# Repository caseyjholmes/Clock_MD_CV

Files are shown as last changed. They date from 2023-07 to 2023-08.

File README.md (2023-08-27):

# Clock_MD_CV
Modified 4HP 2 channel CV controlled clock multiplier and divider Eurorack Module originally by HAGIWO with PSI power and CV input modifications drawn onto PCB by:
HOLMES MODULAR 7-17-23

Just print a PCB, panel and assemeble acording to BOM. Then program with arduino IDE or atmel studio. 
Check back soon for a note here when the module has been tested and completed/finalized. 7-17-23

This module has been tested and completed. The updated firmware has also been posted. Youtube videos to be posted soon as well as Modular Grid data. 8-23-23
Update: Here's a youtube video showing the module purpose and operation. https://youtu.be/xJtNhXA8xrQ?si=LwXfrnCbjALYdgvX
Modular Grid link coming soon. 
Thanks Hagiwo! I hope my additions are pleasing. 

A BOM update has been added to reflect use of LM40405.0 reference shunt instead of lm40412. This change was a necessary correction due to using renamed component packages in eagle. 8-24-23
This change was also updated in the bottom bom CSV files and schematic.

View this module on Modular Grid
https://www.modulargrid.net/e/other-unknown-holmes-modular-clock-md-cv

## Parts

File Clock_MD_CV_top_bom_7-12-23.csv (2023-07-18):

Comment | Designator | Footprint | LCSC Part #
2.2K bead | L1 | 0603
100n | C4 C13 | C0805K

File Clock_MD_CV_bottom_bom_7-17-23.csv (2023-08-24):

Comment | Designator | Footprint | LCSC Part #
1K | R8 | R0805
1N4148WSF-7 | D5 | SOD-323F
1k | R4 R6 | R0805
10k | R9 R18 | R0805
10n | C7 C8 | C0805K
18p | C9 C10 | C0805K
20mhz | Y1 | CRYSTAL-SMD-5X3.2-2PAD
22k | R2 | R0805
22uf | C1 C2 C5 | PANASONIC_C
100k | R10 R11 R12 R13 R14 R15 R16 R17 | R0805
100n | C6 C11 C12 | C0805K
470 | R1 R3 R5 R7 | R0805
470n | C3 | C0805K
ATMEGA328P | IC1 | TQFP32-08
BAT54CLT1G | D4 | SOT23-3
BAT54SLT1G | D1 D2 D3 | SOT23
FIDUCIAL1X2 | FD1 FD2 FD3 | FIDUCIAL-1X2
LM40405.0 | IC2 | DBZ_R-PDSO-G3
MB1S | B1 | SOIC-4
MCP6002_ | IC4 | SO08
REG1117 | IC3 | SOT223

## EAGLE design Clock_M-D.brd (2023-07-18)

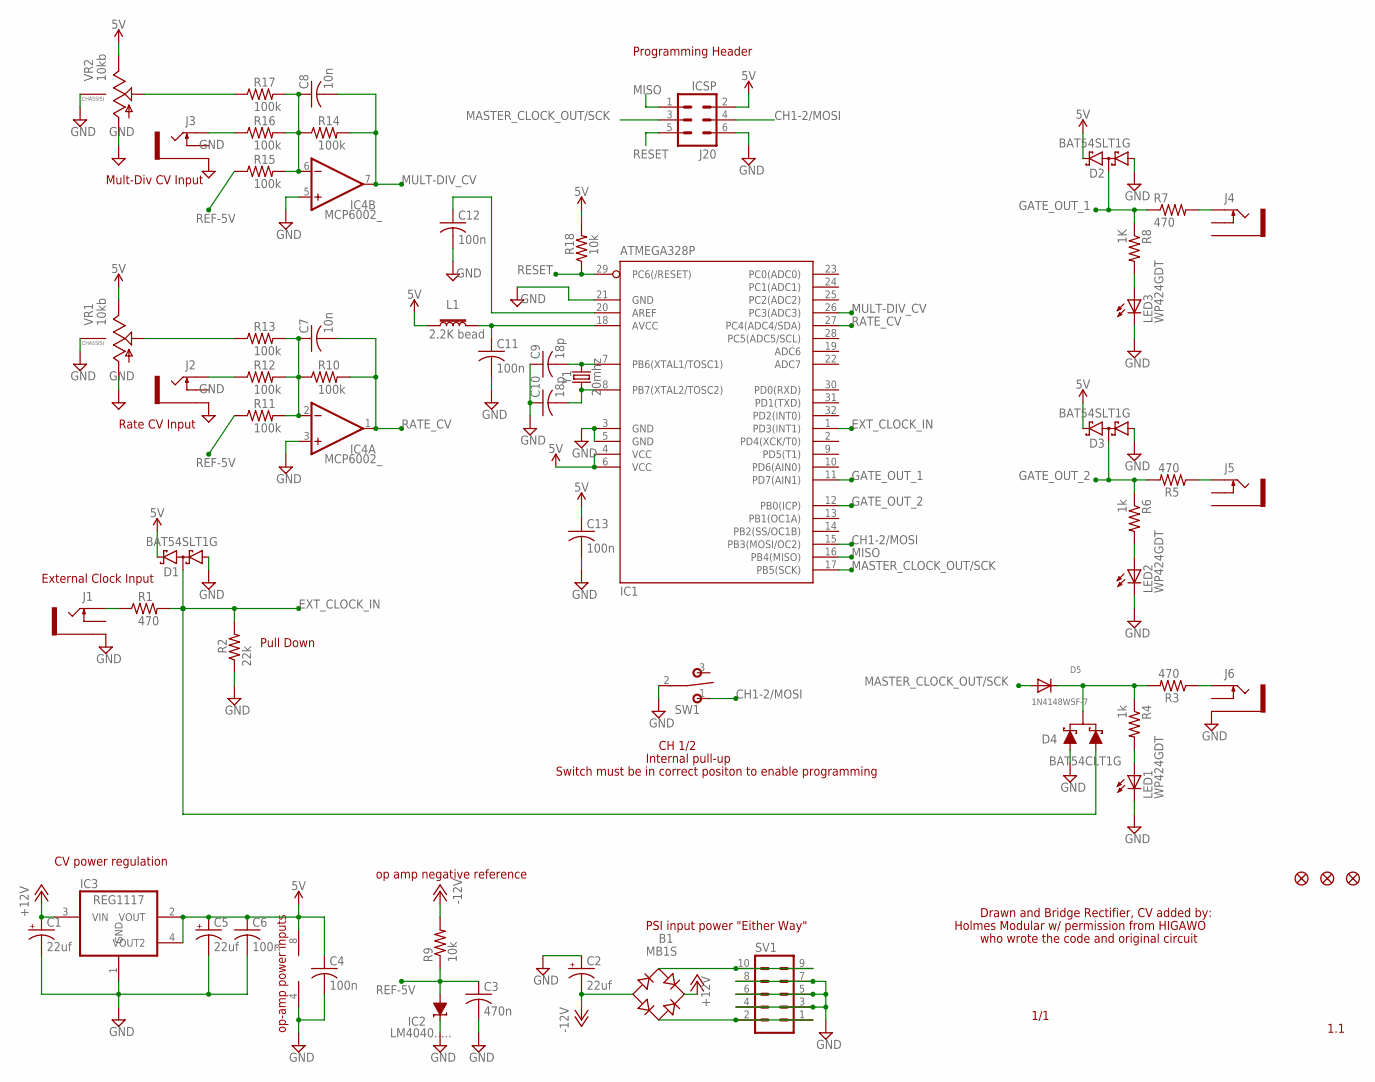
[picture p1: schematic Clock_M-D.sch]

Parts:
B1: MB1S; SOIC-4
C1, C2, C5: 22uf; PANASONIC_C
C3: 470n; C0805K
C4, C6, C11, C12, C13: 100n; C0805K
C7, C8: 10n; C0805K
C9, C10: 18p; C0805K
D1, D2, D3: BAT54SLT1G; SOT23
D4: BAT54CLT1G; SOT23-3
D5: 1N4148WSF-7; SOD-323F
FD1, FD2, FD3: FIDUCIAL1X2; FIDUCIAL-1X2
IC1: ATMEGA328P; TQFP32-08
IC2: LM4040.....; DBZ_R-PDSO-G3
IC3: REG1117; SOT223
IC4: MCP6002_; SO08
J1, J2, J3, J4, J5, J6: THONKICONNNEW; WQP-PJ301M-12_JACK
J20: ICSP; MA03-2
L1: 2.2K bead; 0603
LED1, LED2, LED3: WP424GDT; LED3MM
R1, R3, R5, R7: 470; R0805
R2: 22k; R0805
R4, R6: 1k; R0805
R8: 1K; R0805
R9, R18: 10k; R0805
R10, R11, R12, R13, R14, R15, R16, R17: 100k; R0805
SV1: EURO_POWER_HEADERLOCK; 10PIN_BACKSIDE
SW1: T-80-T-SPDT-ON-OFF-ON; M9040P
VR1, VR2: 10kb; 9MM_SNAP-IN_POT
Y1: 20mhz; CRYSTAL-SMD-5X3.2-2PAD

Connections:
5V: C4.1, C5.+, C6.1, C13.1, D1.2 (C2), D2.2 (C2), D3.2 (C2), IC1.4 (VCC), IC1.6 (VCC), IC3.2 (VOUT), IC3.4 (VOUT2), IC4.8 (V+), J20.2, L1.1, R18.2, VR1.3 (E), VR2.3 (E)
+12V: B1.+, C1.+, IC3.3 (VIN)
-12V: B1.-, C2.-, R9.2
CH1-2/MOSI: IC1.15 (PB3(MOSI/OC2)), J20.4, SW1.1 (O)
EXT_CLOCK_IN: D1.3 (C1A2), D4.2 (A1), IC1.1 (PD3(INT1)), R1.2, R2.2
GATE_OUT_1: D2.3 (C1A2), IC1.11 (PD7(AIN1)), R7.1, R8.1
GATE_OUT_2: D3.3 (C1A2), IC1.12 (PB0(ICP)), R5.2, R6.1
GND: C1.-, C2.+, C3.2, C4.2, C5.-, C6.2, C9.1, C10.1, C11.2, C12.2, C13.2, D1.1 (A1), D2.1 (A1), D3.1 (A1), D4.1 (A), IC1.3 (GND), IC1.5 (GND), IC1.21 (GND), IC2.1 (C), IC3.1 (GND), IC4.3 (+IN), IC4.4 (V-), IC4.5 (+IN), J1.P$3_SLEEVE (SLEEVE), J2.P$3_SLEEVE (SLEEVE), J3.P$3_SLEEVE (SLEEVE), J6.P$3_SLEEVE (SLEEVE), J20.6, LED1.K (C), LED2.K (C), LED3.K (C), R2.1, SV1.3, SV1.4, SV1.5, SV1.6, SV1.7, SV1.8, SW1.2, VR1.1 (A), VR1.CHASSIS1, VR1.CHASSIS2, VR2.1 (A), VR2.CHASSIS1, VR2.CHASSIS2
MASTER_CLOCK_OUT/SCK: D5.A, IC1.17 (PB5(SCK)), J20.3
MISO: IC1.16 (PB4(MISO)), J20.1
MULT-DIV_CV: C8.2, IC1.26 (PC3(ADC3)), IC4.7 (OUT), R14.2
unnamed: B1.~1 (AC1), SV1.9, SV1.10
unnamed: B1.~2 (AC2), SV1.1, SV1.2
unnamed: J1.P$1_TIP (TIP), R1.1
unnamed: D4.3 (C), D5.C, R3.2, R4.1
unnamed: LED1.A, R4.2
unnamed: J6.P$1_TIP (TIP), R3.1
unnamed: LED2.A, R6.2
unnamed: J5.P$1_TIP (TIP), R5.1
unnamed: J4.P$1_TIP (TIP), R7.2
unnamed: LED3.A, R8.2
unnamed: C7.1, IC4.2 (-IN), R10.1, R11.2, R12.2, R13.2
unnamed: J2.P$1_TIP (TIP), R12.1
unnamed: R13.1, VR1.2 (S)
unnamed: R17.1, VR2.2 (S)
unnamed: J3.P$1_TIP (TIP), R16.1
unnamed: C8.1, IC4.6 (-IN), R14.1, R15.2, R16.2, R17.2
unnamed: C11.1, IC1.18 (AVCC), L1.2
unnamed: C9.2, IC1.7 (PB6(XTAL1/TOSC1)), Y1.P$2 (2)
unnamed: C10.2, IC1.8 (PB7(XTAL2/TOSC2)), Y1.P$1 (1)
unnamed: C12.1, IC1.20 (AREF)
RATE_CV: C7.2, IC1.27 (PC4(ADC4/SDA)), IC4.1 (OUT), R10.2
REF-5V: C3.1, IC2.2 (A), R9.1, R11.1, R15.1
RESET: IC1.29 (PC6(/RESET)), J20.5, R18.1

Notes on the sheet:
CH 1/2
Internal pull-up
1/1
1.1
Holmes Modular w/ permission from HIGAWO
Drawn and Bridge Rectifier, CV added by:
who wrote the code and original circuit
op-amp power inputs
op amp negative reference
PSI input power "Either Way"
External Clock Input
CV power regulation
Rate CV Input
Mult-Div CV Input
Programming Header
Pull Down
Switch must be in correct positon to enable programming

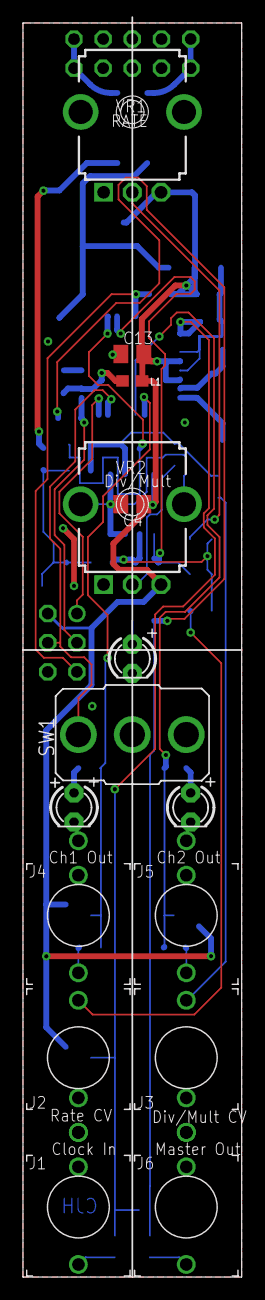
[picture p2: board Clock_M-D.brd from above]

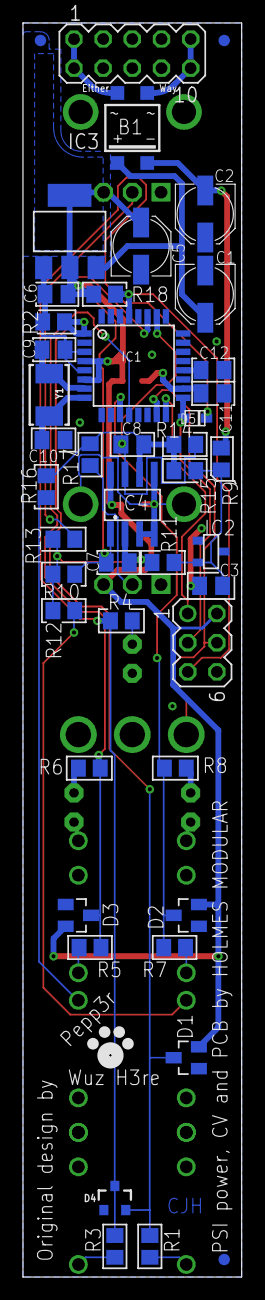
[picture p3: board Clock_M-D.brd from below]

Board: 2 copper layers, 19.1 x 109.2 mm, 60 parts (44 on the bottom side), 34 nets.

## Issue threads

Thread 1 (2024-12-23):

REG1117

ijnekenamay, 2024-12-23:
Hi, thank you for the great update from the HAGIWO module.
Just to confirm one point, the 1117 regulator has many variations in its output voltage.
From checking the schematic, I think it is the 1117-5V that should be clearly stated in the BOM.

Please correct if it is not too much for you.
Thanks.

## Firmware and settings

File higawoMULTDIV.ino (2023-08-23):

//Clock M_D module
#include <MsTimer2.h>

unsigned long ext_count = 400;//タイマーカウント用
unsigned long old_ext_pulse = 0;
unsigned long old_int_pulse = 0;
unsigned long ext_period = 0;//周期
unsigned long ext_count_result = 0;//タイマーのカウント結果
unsigned long old_ext_count_result = 0;//タイマーのカウント結果
byte ext_pulse = 0;//外部クロック　あれば1、なければ0
byte int_pulse = 0;//内部クロック
byte ext_injudge = 1;//外部入力有無判定。あれば1,なければ0。タイマーカウントが規定値超えると判定切り替え
byte old_ext_injudge = 2;

int AD_rate = 512;//rateノブの入力
int rate = 1000;//内部クロック動作時に使用

int AD_MD = 512;//MDノブの入力値
int out_width_ch1 = 10;//アウトプットのパルス幅。
int out_width_ch2 = 10;//アウトプットのパルス幅。
int old_AD_MD = 512;//SW切り替え時のRATE値誤読対策
int MD_ch1 = 5;//マルチプル、ディバイダー判定ch1
int MD_ch2 = 5;//マルチプル、ディバイダー判定ch2
int M_period_ch1 = 0;//マルチプルの時、出力クロックの周期。マルチプルでなければ0とする。
int M_period_ch2 = 0;//マルチプルの時、出力クロックの周期。マルチプルでなければ0とする。
int M_count_ch1 = 1;//マルチプルの時、パルスごとにカウントし、設定値に達すると0に戻る
int M_count_ch2 = 1;//マルチプルの時、パルスごとにカウントし、設定値に達すると0に戻る
int D_count_ch1 = 1;//外部パルスが入るとカウントを位置上げる
int D_count_ch2 = 1;//外部パルスが入るとカウントを位置上げる
int D_full_ch1 = 1;//カウントの上限値
int D_full_ch2 = 1;//カウントの上限値
byte CH1out = 0;//0でLOW出力、1でHIGH出力
byte CH2out = 0;//0でLOW出力、1でHIGH出力
byte M_done_ch1 = 0; //マルチプルの出力確認用。ないと、1クロックで複数パルスでてしまう
byte M_done_ch2 = 0; //マルチプルの出力確認用。ないと、1クロックで複数パルスでてしまう


//---mode切り替え-------------
byte mode_sw = 1;
byte mode = 1;//1=CH1,2=CH2
byte old_mode = 0;//SW切り替え時のRATE値誤読対策
int old_MD_ch1 = 0;//スイッチ切り替え時にディバイダーのクロックが狂うバグ対策
int old_MD_ch2 = 0;//スイッチ切り替え時にディバイダーのクロックが狂うバグ対策

void setup() {
 pinMode(7, OUTPUT); //CH1out
 pinMode(8, OUTPUT); //CH2out
 pinMode(13, OUTPUT); //internal_clock_out
 pinMode(11, INPUT_PULLUP); //SW
 pinMode(3, INPUT); //ext_clock_in
 Serial.begin(9600);

 MsTimer2::set(1, timer_count); // 1ms毎にタイマーカウント
 MsTimer2::start();//外部入力Highになったら、次のHighまでカウント
}

void loop() {
 AD_MD = analogRead(3);
 AD_rate = analogRead(4); //removed AD_rate = 1023 - analogRead(4);
 rate = AD_rate * 2 + 100;

 old_ext_pulse = ext_pulse;
 old_int_pulse = int_pulse;
 ext_pulse = digitalRead(3);

 mode_sw = digitalRead(11);
 old_mode = mode;

 old_ext_injudge = ext_injudge;

 //-----------ディバイダー出力のカウントリセット------------
 if (D_count_ch1 >= D_full_ch1) {
   D_count_ch1 = 0;
 }
 if (D_count_ch2 >= D_full_ch2) {
   D_count_ch2 = 0;
 }

 //-----------SWの読み取り---------------

 old_MD_ch1 = MD_ch1;//スイッチ切り替え時にディバイダーのクロックが狂うバグ対策
 old_MD_ch2 = MD_ch2;//スイッチ切り替え時にディバイダーのクロックが狂うバグ対策

 if ( mode_sw == 1  ) {
   mode = 1;
 }
 else if (mode_sw == 0  ) {
   mode = 2;
 }

 if ( old_mode != mode ) {//スイッチ切り替え時にディバイダーのクロックが狂うバグ対策
   old_AD_MD = AD_MD;
 }

 //---------MDノブ判定-----------------------

 if ( mode == 1 && abs(old_AD_MD - AD_MD ) > 30) { //absはスイッチ切り替え時にディバイダーのクロックが狂うバグ対策
   old_AD_MD = 1200;//abs(old_AD_MD - AD_MD ) > 30が絶対に成立するため

   if ( AD_MD >= 0 && AD_MD < 20) {
     MD_ch1 = 1;//*16
   }

   else if ( AD_MD >= 20 && AD_MD < 90) {
     MD_ch1 = 2;//*8
   }

   else if ( AD_MD >= 90 && AD_MD < 240) {
     MD_ch1 = 3;//*4
   }

   else if ( AD_MD >= 240 && AD_MD < 400) {
     MD_ch1 = 4;//*2
   }

   else if ( AD_MD >= 400 && AD_MD < 550) {
     MD_ch1 = 5;//*1
   }

   else if ( AD_MD >= 550 && AD_MD < 700) {
     MD_ch1 = 6;//1/2
   }

   else if ( AD_MD >= 700 && AD_MD < 820) {
     MD_ch1 = 7;//1/3
   }

   else if ( AD_MD >= 820 && AD_MD < 960) {
     MD_ch1 = 8;//1/4
   }

   else if ( AD_MD >= 960 && AD_MD < 1024) {
     MD_ch1 = 9;//1/8
   }
 }

 else if ( mode == 2 && abs(old_AD_MD - AD_MD ) > 30) {  //absはスイッチ切り替え時にディバイダーのクロックが狂うバグ対策
   old_AD_MD = 1200;//abs(old_AD_MD - AD_MD ) > 30が絶対に成立するため

   if ( AD_MD >= 0 && AD_MD < 20) {
     MD_ch2 = 1;//*16
   }

   else if ( AD_MD >= 20 && AD_MD < 90) {
     MD_ch2 = 2;//*8
   }

   else if ( AD_MD >= 90 && AD_MD < 240) {
     MD_ch2 = 3;//*4
   }

   else if ( AD_MD >= 240 && AD_MD < 400) {
     MD_ch2 = 4;//*2
   }

   else if ( AD_MD >= 400 && AD_MD < 550) {
     MD_ch2 = 5;//*1
   }

   else if ( AD_MD >= 550 && AD_MD < 700) {
     MD_ch2 = 6;//1/2
   }

   else if ( AD_MD >= 700 && AD_MD < 820) {
     MD_ch2 = 7;//1/3
   }

   else if ( AD_MD >= 820 && AD_MD < 960) {
     MD_ch2 = 8;//1/4
   }

   else if ( AD_MD >= 960 && AD_MD < 1024) {
     MD_ch2 = 9;//1/8
   }
 }


 switch (MD_ch1) {
   case 1:
     out_width_ch1 = ext_period / 2 / 8;
     M_period_ch1 = ext_period / 8;
     break;

   case 2:
     out_width_ch1 = ext_period / 2 / 4;
     M_period_ch1 = ext_period / 4;
     break;

   case 3:
     out_width_ch1 = ext_period / 2 / 3;
     M_period_ch1 = ext_period / 3;
     break;

   case 4:
     out_width_ch1 = ext_period / 2 / 2;
     M_period_ch1 = ext_period / 2;
     break;

   case 5:
     out_width_ch1 = ext_period / 2 ;
     M_period_ch1 = 0;
     D_full_ch1 = 1;
     break;

   case 6:
     out_width_ch1 = ext_period / 2;
     M_period_ch1 = 0;
     D_full_ch1 = 2;
     break;

   case 7:
     out_width_ch1 = ext_period / 2;
     M_period_ch1 = 0;
     D_full_ch1 = 4;
     break;

   case 8:
     out_width_ch1 = ext_period / 2;
     M_period_ch1 = 0;
     D_full_ch1 = 8;
     break;

   case 9:
     out_width_ch1 = ext_period / 2;
     M_period_ch1 = 0;
     D_full_ch1 = 16;
     break;
 }


 switch (MD_ch2) {
   case 1:
     out_width_ch2 = ext_period / 2 / 8;
     M_period_ch2 = ext_period / 8;
     break;

   case 2:
     out_width_ch2 = ext_period / 2 / 4;
     M_period_ch2 = ext_period / 4;
     break;

   case 3:
     out_width_ch2 = ext_period / 2 / 3;
     M_period_ch2 = ext_period / 3;
     break;

   case 4:
     out_width_ch2 = ext_period / 2 / 2;
     M_period_ch2 = ext_period / 2;
     break;

   case 5:
     out_width_ch2 = ext_period / 2 ;
     M_period_ch2 = 0;
     D_full_ch2 = 1;
     break;

   case 6:
     out_width_ch2 = ext_period / 2 ;
     M_period_ch2 = 0;
     D_full_ch2 = 2;
     break;

   case 7:
     out_width_ch2 = ext_period / 2 ;
     M_period_ch2 = 0;
     D_full_ch2 = 4;
     break;

   case 8:
     out_width_ch2 = ext_period / 2 ;
     M_period_ch2 = 0;
     D_full_ch2 = 8;
     break;

   case 9:
     out_width_ch2 = ext_period / 2 ;
     M_period_ch2 = 0;
     D_full_ch2 = 16;
     break;
 }

 if ( MD_ch1 != old_MD_ch1 || MD_ch2 != old_MD_ch2 ) { //スイッチ切り替え時にディバイダーのクロックが狂うバグ対策
   D_count_ch1 = 0;
   D_count_ch2 = 0;
 }

 //------------外部入力有無判定-------------------------------
 if ( ext_count > 4000 ) { //4s以上カウントが無ければ、外部入力無し判定
   ext_injudge = 0;
 }
 else if ( ext_count < 4000 && ext_pulse == 1 ) {
   ext_injudge = 1;
 }

 if ( old_ext_injudge == 1 && ext_injudge == 0 ) { //外部入力が有→無のとき
   ext_count = 0;
 }


 //---------クロック設定------------------------
 if ( ext_injudge != 0 ) { //外部クロックを使用
   if (ext_pulse == 1 && old_ext_pulse == 0) {
     old_ext_count_result = ext_count_result;//2回の平均取る用
     ext_count_result = ext_count;
     //            ext_count = 0;
     ext_period = (old_ext_count_result + ext_count_result) / 2;//外部入力周期。ばらつき低減のため2回の平均値
     //      MsTimer2::start();//外部入力Highになったら、次のHighまでカウント
   }
 }
 else if ( ext_injudge == 0) { //内部クロックを使用
   ext_period = rate;
   if ( ext_count < 5 || ext_count >= ext_period) {
     int_pulse = 1;
   }
   else if (ext_count >= 5 ) {
     int_pulse = 0;
   }

 }
 //--------------INTERNAL CLOCK出力（外部入力無い場合のみ）-----------

 if ( int_pulse == 1 ) {
   digitalWrite(13, HIGH);
 }
 else if ( ext_count >= ext_period / 2  ) {
   digitalWrite(13, LOW);
 }

 //-----------------OUT1出力------------------
 if (ext_pulse == 1 && old_ext_pulse == 0) {//外部クロック用
   D_count_ch1 ++;
   ext_count = 0;
   M_count_ch1 = 0;
   M_done_ch1 = 0;
   if ( MD_ch1 <= 4 ) {
     digitalWrite(7, HIGH);
     CH1out = 1;
   }
 }

 if (int_pulse == 1 && old_int_pulse == 0) {//内部クロック用
   D_count_ch1 ++;
   ext_count = 0;
   M_count_ch1 = 0;
   M_done_ch1 = 0;
   if ( MD_ch1 <= 4 ) {
     digitalWrite(7, HIGH);
     CH1out = 1;
   }
 }

 if ( MD_ch1 < 5 ) {
   if ( ext_count  >= M_period_ch1  * M_count_ch1  && CH1out == 0) {
     CH1out = 1;
     digitalWrite(7, HIGH);
   }
   if ( ext_count >= M_period_ch1  * M_count_ch1 + out_width_ch1  && CH1out == 1 ) {
     digitalWrite(7, LOW);
     M_count_ch1 ++;
     CH1out = 0;
   }
 }

 else if ( MD_ch1 == 5 ) {
   if (D_count_ch1 == 1 && M_done_ch1 == 0) {
     CH1out = 1;
     M_done_ch1 = 1;
     digitalWrite(7, HIGH);
   }
   if ( ext_count >=  out_width_ch1   ) {
     digitalWrite(7, LOW);
     CH1out = 0;
   }
 }

 else if ( MD_ch1 > 5 ) {
   if (D_count_ch1 == 1 && M_done_ch1 == 0) {
     CH1out = 1;
     digitalWrite(7, HIGH);
     M_done_ch1 = 1;
   }
   if ( ext_count >=  out_width_ch1   ) {
     digitalWrite(7, LOW);
     CH1out = 0;
   }
 }


 //-----------------OUT2出力------------------
 if (ext_pulse == 1 && old_ext_pulse == 0) {
   D_count_ch2 ++;
   M_count_ch2 = 0;
   M_done_ch2 = 0;
   if ( MD_ch2 <= 4 ) {
     digitalWrite(8, HIGH);
     CH2out = 1;
   }
 }

 if (int_pulse == 1 && old_int_pulse == 0) {//内部クロック用
   D_count_ch2 ++;
   M_count_ch2 = 0;
   M_done_ch2 = 0;
   if ( MD_ch2 <= 4 ) {
     digitalWrite(8, HIGH);
     CH2out = 1;
   }
 }

 if ( MD_ch2 < 5 ) {
   if ( ext_count  >= M_period_ch2  * M_count_ch2  && CH2out == 0) {
     CH2out = 1;
     digitalWrite(8, HIGH);
   }
   if ( ext_count >= M_period_ch2  * M_count_ch2 + out_width_ch2  && CH2out == 1 ) {
     digitalWrite(8, LOW);
     M_count_ch2 ++;
     CH2out = 0;
   }
 }

 else if ( MD_ch2 == 5 ) {
   if (D_count_ch2 == 1 && M_done_ch2 == 0) {
     CH2out = 1;
     M_done_ch2 = 1;
     digitalWrite(8, HIGH);
   }
   if ( ext_count >=  out_width_ch2   ) {
     digitalWrite(8, LOW);
     CH2out = 0;
   }
 }

 else if ( MD_ch2 > 5 ) {
   if (D_count_ch2 == 1 && M_done_ch2 == 0) {
     CH2out = 1;
     M_done_ch2 = 1;
     digitalWrite(8, HIGH);
   }
   if ( ext_count >=  out_width_ch2   ) {
     digitalWrite(8, LOW);
     CH2out = 0;
   }
 }


 //開発用

 Serial.print(ext_count);
 Serial.print(",");
 Serial.print(CH1out * 500);
 Serial.print(",");
 Serial.print(D_count_ch1 * 80);
 Serial.println("");

}

//タイマーカウント。1ms毎にカウントを増やす
void timer_count() {
 ext_count ++;
}

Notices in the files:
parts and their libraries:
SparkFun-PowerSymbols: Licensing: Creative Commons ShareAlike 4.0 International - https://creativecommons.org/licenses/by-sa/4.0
